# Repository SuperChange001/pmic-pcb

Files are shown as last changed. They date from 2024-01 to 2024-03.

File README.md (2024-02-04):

# Elastic Power Module

This repository contains the design and related files for the Elastic Power Module.

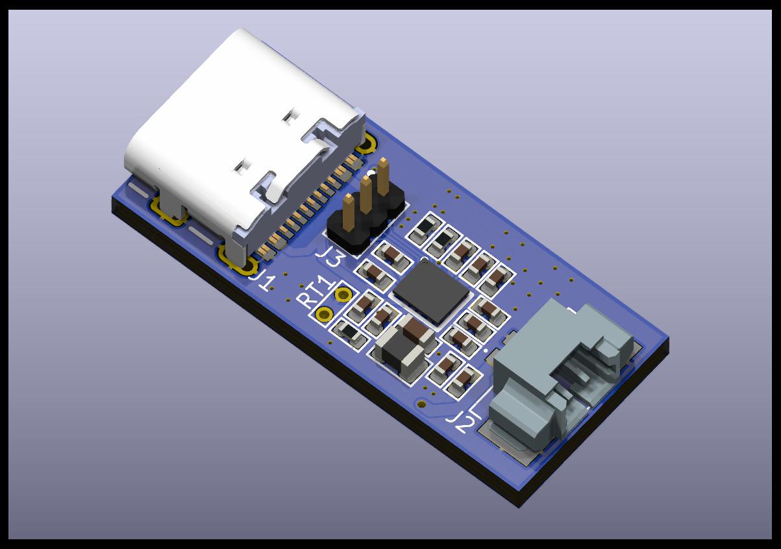
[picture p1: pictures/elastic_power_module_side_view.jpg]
Elastic Power Module


## Current Status
- [x] Schematic
- [x] PCB Design
- [x] Prototype
- [ ] Testing (** It is not tested yet, DO NOT use it as your reference design! **)
  - know issues:
    - in the default configuration, the nRST pin should be pulled up to VSYS, but right now it is floating.
      - should further check if I always need to have the external pull-up resistor or I can use the internal pull-up resistor of the microcontroller.
      - and how convinent it is to keep current circuit and configure the IC via microcontroller.
    - VIO should be connected to the header or a test pad, so we can configure the IC without flying a wire.

## Project Structure

- `elastic_power_module.kicad_pcb`: KiCad PCB design file.
- `elastic_power_module.kicad_prl`: KiCad project local settings file.
- `elastic_power_module.kicad_pro`: KiCad project file.
- `elastic_power_module.kicad_sch`: KiCad schematic file.
- `elastic_power_module.pdf`: PDF version of the schematic.
- `fp-info-cache`: Footprint info cache.
- `pictures`: Contains pictures of the assembled module.
  - `elastic_power_module_bottom_view.jpg`: Bottom view of the module.
  - `elastic_power_module_side_view.jpg`: Side view of the module.
  - `elastic_power_module_top_view.jpg`: Top view of the module.~

## Getting Started

- To get started with this project, clone the repository and open the `.kicad_pcb` or `.kicad_sch` files in KiCad.
- Or you can just download the PDF version of the schematic and use it as your reference design.
- To assemble the module, you can use the interactive BOM file [here](https://htmlpreview.github.io/?https://github.com/SuperChange001/pmic-pcb/blob/master/bom/ibom.html).

## Contributing

Contributions are welcome. Please open an issue to discuss your idea or submit a Pull Request.

## License

[MIT](https://choosealicense.com/licenses/mit/)~~~

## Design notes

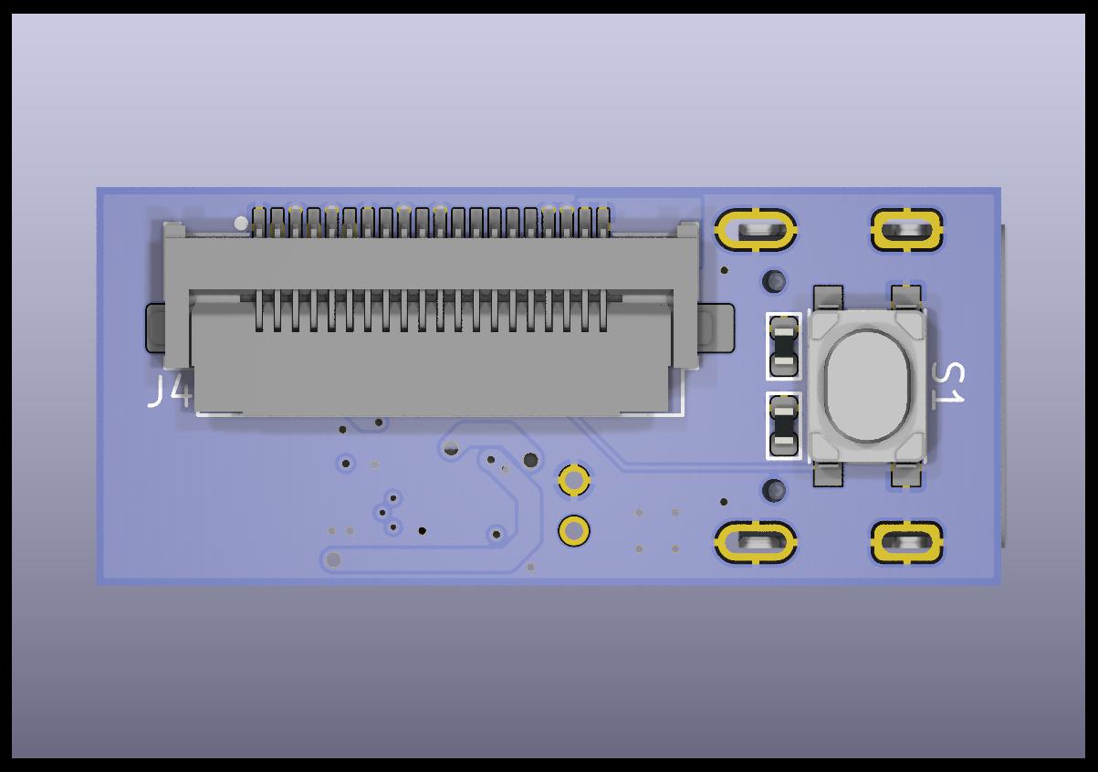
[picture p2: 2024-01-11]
pictures/elastic_power_module_bottom_view.jpg

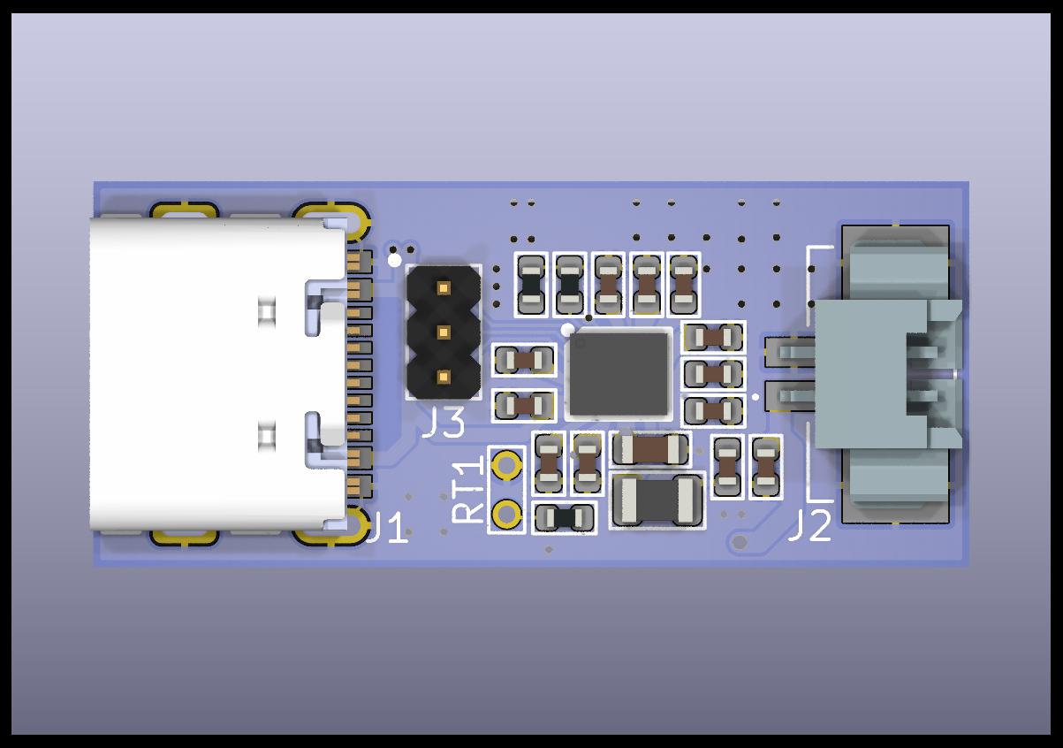
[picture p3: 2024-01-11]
pictures/elastic_power_module_top_view.jpg

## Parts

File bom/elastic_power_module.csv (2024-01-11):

null | Sourced | Placed | References | Value | Footprint | Quantity
1 |  |  | C1, C2, C3, C10, C15 | 22uF | C_0402 | 5
2 |  |  | C6, C7, C13, C14 | 1uF | C_0402 | 4
3 |  |  | C9, C12 | 4.7uF | C_0402 | 2
4 |  |  | C4 | 22uF | C_0603 | 1
5 |  |  | C5 | 3300pF | C_0402 | 1
6 |  |  | R4, R5 | 5K | R_0402 | 2
7 |  |  | R8, R9 | 10K | R_0402 | 2
8 |  |  | R10 | 100K | R_0402 | 1
9 |  |  | L1 | DFE201612E-2R2M | L_0806 | 1
10 |  |  | U1 | MAX77654AENV+T | BGA30C40P6X5_279X234X50 | 1
11 |  |  | RT1 | NTCLE413E2103H400 | THT2 | 1
12 |  |  | S1 | TL3365AF180QG | TL3365AF180QG | 1
13 |  |  | J1 | USB4105GFA060 | GCT_USB4105GFA060 | 1
14 |  |  | J2 | 53261-0271 | 53261-0271 | 1
15 |  |  | J3 | ~ | Header_THT_1.27_3P | 1
16 |  |  | J4 | ~ | Connector_20PIN_5052782033 | 1

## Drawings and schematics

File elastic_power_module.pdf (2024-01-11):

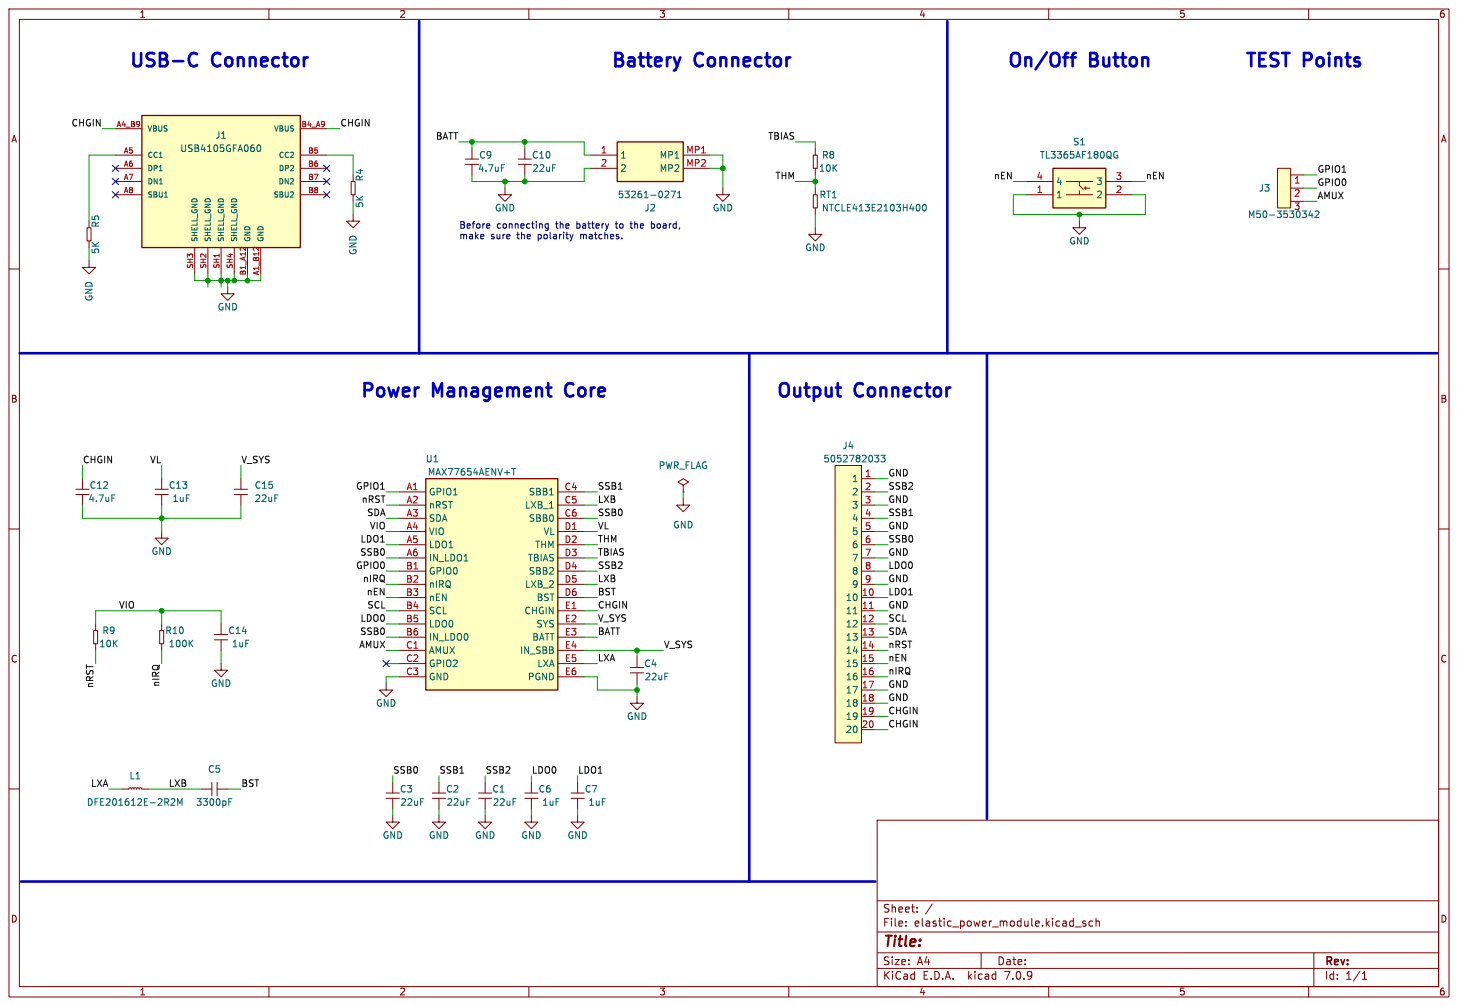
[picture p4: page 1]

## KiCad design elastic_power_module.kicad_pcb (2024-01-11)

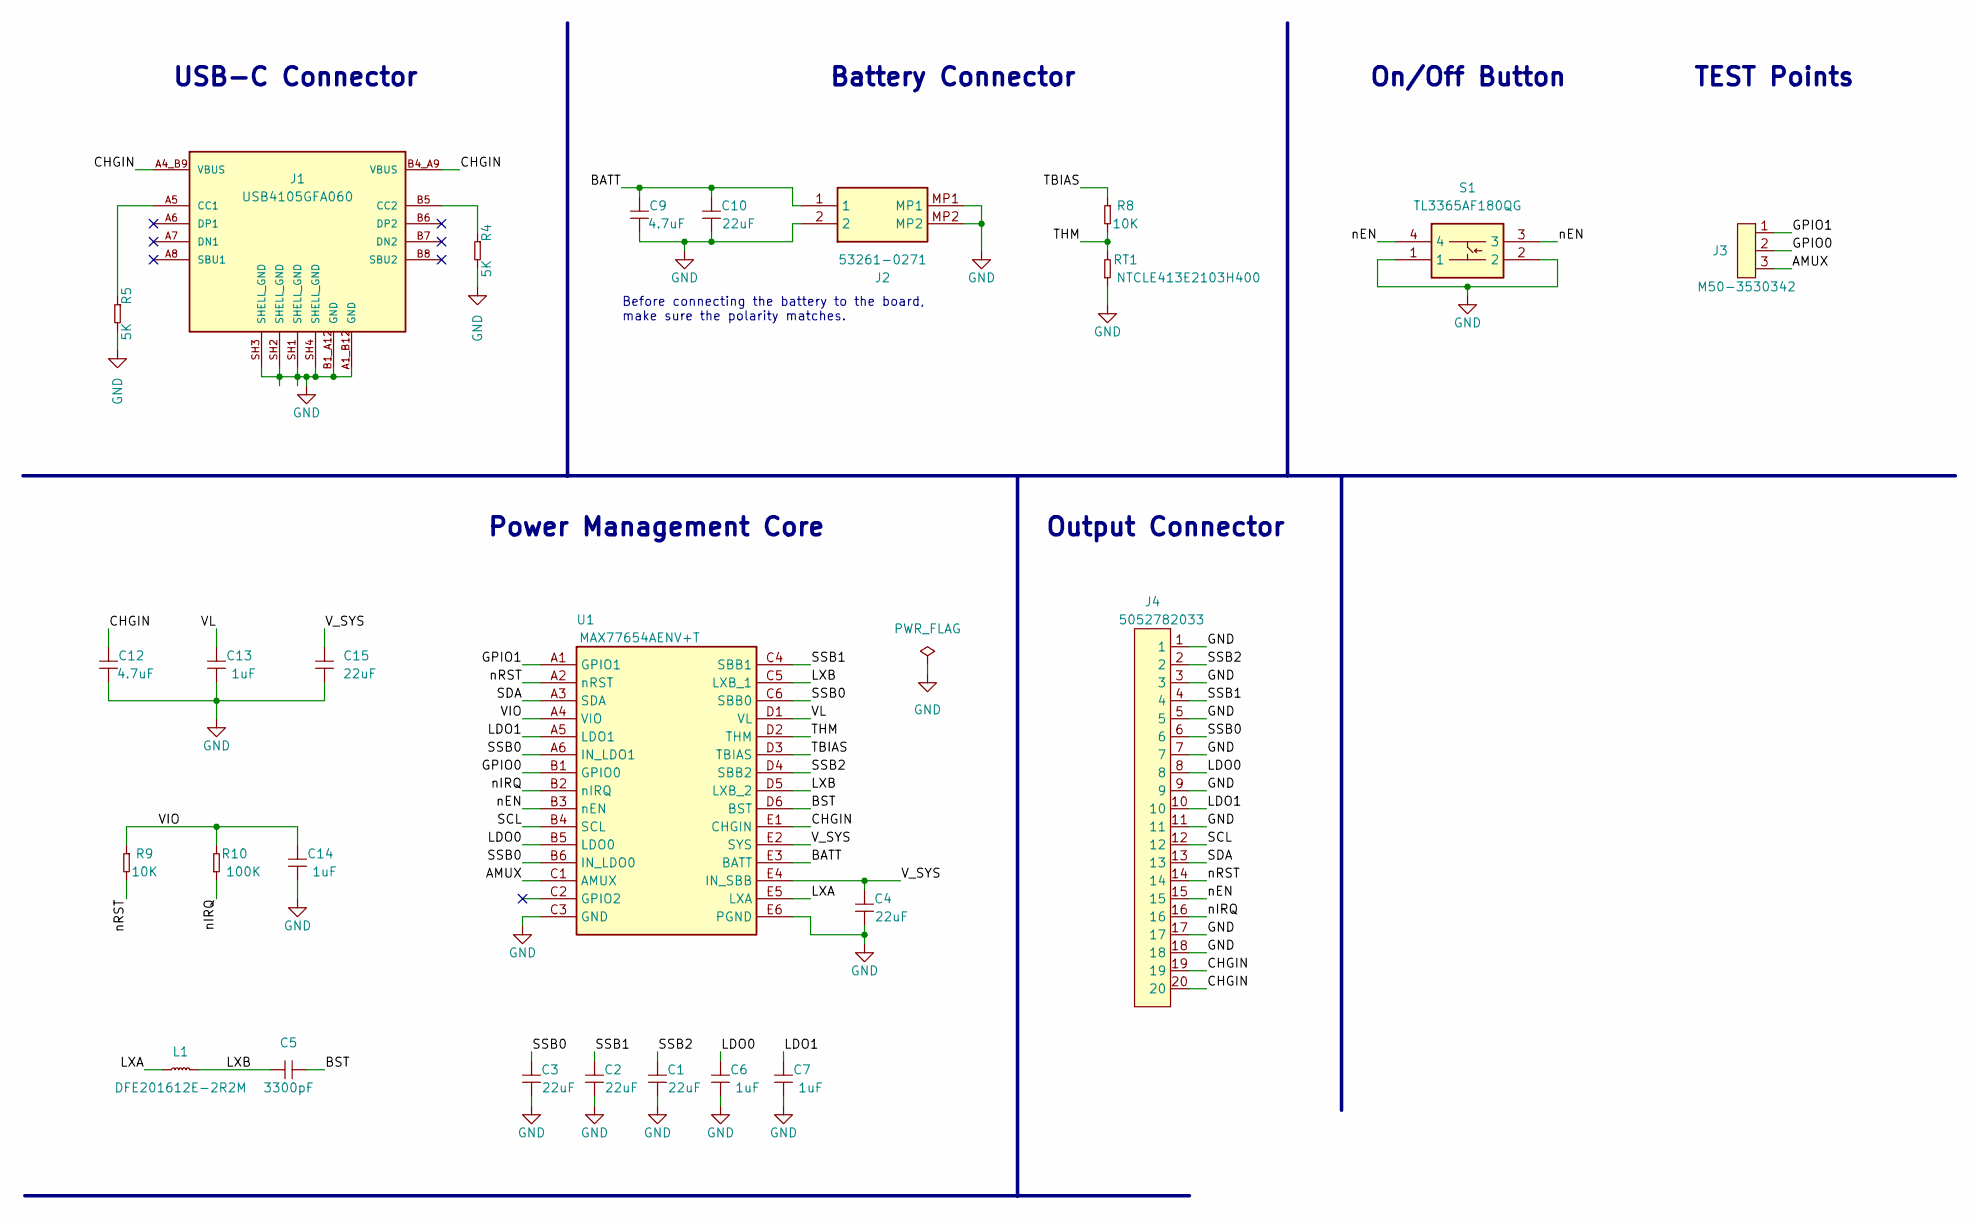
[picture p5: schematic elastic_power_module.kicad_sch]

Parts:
C1, C2, C3, C10, C15: 22uF; C_0402
C4: 22uF; C_0603
C5: 3300pF; C_0402
C6, C7, C13, C14: 1uF; C_0402
C9, C12: 4.7uF; C_0402
J1: USB4105GFA060; GCT_USB4105GFA060
J2: 53261-0271; Mouser Part Number 538-53261-0271
J3: M50-3530342; Header_THT_1.27_3P
J4: 5052782033; Connector_20PIN_5052782033
L1: DFE201612E-2R2M; L_0806
R4, R5: 5K; R_0402
R8, R9: 10K; R_0402
R10: 100K; R_0402
RT1: NTCLE413E2103H400; THT2
S1: TL3365AF180QG; Mouser Part Number 612-TL3365AF180QG
U1: MAX77654AENV+T; BGA30C40P6X5_279X234X50; Mouser Part Number 700-MAX77654AENV+T

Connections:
/AMUX: J3.3, U1.C1 (AMUX)
/BATT: C9.2, C10.1, J2.1, U1.E3 (BATT)
/BST: C5.1, U1.D6 (BST)
/CHGIN: C12.2, J1.A4_B9 (VBUS), J1.B4_A9 (VBUS), J4.19, J4.20, U1.E1 (CHGIN)
/GPIO0: J3.2, U1.B1 (GPIO0)
/GPIO1: J3.1, U1.A1 (GPIO1)
/LDO0: C6.1, J4.8, U1.B5 (LDO0)
/LDO1: C7.1, J4.10, U1.A5 (LDO1)
/LXA: L1.1, U1.E5 (LXA)
/LXB: C5.2, L1.2, U1.C5 (LXB_1), U1.D5 (LXB_2)
/SCL: J4.12, U1.B4 (SCL)
/SDA: J4.13, U1.A3 (SDA)
/SSB0: C3.1, J4.6, U1.A6 (IN_LDO1), U1.B6 (IN_LDO0), U1.C6 (SBB0)
/SSB1: C2.1, J4.4, U1.C4 (SBB1)
/SSB2: C1.1, J4.2, U1.D4 (SBB2)
/TBIAS: R8.2, U1.D3 (TBIAS)
/THM: R8.1, RT1.1, U1.D2 (THM)
/VIO: C14.1, R9.2, R10.1, U1.A4 (VIO)
/VL: C13.1, U1.D1 (VL)
/V_SYS: C4.1, C15.1, U1.E2 (SYS), U1.E4 (IN_SBB)
/nEN: J4.15, S1.3, S1.4, U1.B3 (nEN)
/nIRQ: J4.16, R10.2, U1.B2 (nIRQ)
/nRST: J4.14, R9.1, U1.A2 (nRST)
GND: C1.2, C2.2, C3.2, C4.2, C6.2, C7.2, C9.1, C10.2, C12.1, C13.2, C14.2, C15.2, J1.A1_B12 (GND), J1.B1_A12 (GND), J1.SH1 (SHELL_GND), J1.SH2 (SHELL_GND), J1.SH3 (SHELL_GND), J1.SH4 (SHELL_GND), J2.2, J2.MP1, J2.MP2, J4.1, J4.3, J4.5, J4.7, J4.9, J4.11, J4.17, J4.18, R4.1, R5.1, RT1.2, S1.1, S1.2, U1.C3 (GND), U1.E6 (PGND)
unnamed: J1.A5 (CC1), R5.2
unnamed: J1.B5 (CC2), R4.2

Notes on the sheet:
TEST Points
Output Connector
Battery Connector
USB-C Connector
On/Off Button
Power Management Core
Before connecting the battery to the board, make sure the polarity matches.

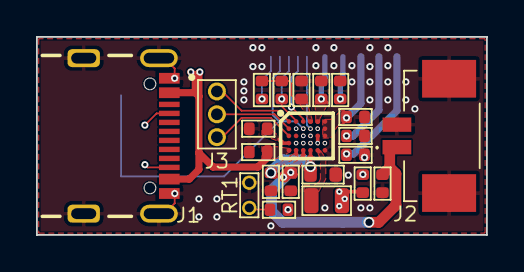
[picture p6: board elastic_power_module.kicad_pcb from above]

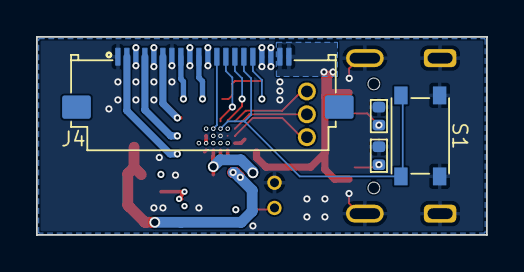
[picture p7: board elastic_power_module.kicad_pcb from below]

Board: 4 copper layers, 25.0 x 11.0 mm, 26 parts (4 on the bottom side), 26 nets.

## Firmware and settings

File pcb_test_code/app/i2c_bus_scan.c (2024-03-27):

/**
 * Copyright (c) 2020 Raspberry Pi (Trading) Ltd.
 *
 * SPDX-License-Identifier: BSD-3-Clause
 */

// Sweep through all 7-bit I2C addresses, to see if any slaves are present on
// the I2C bus. Print out a table that looks like this:
//
// I2C Bus Scan
//   0  1  2  3  4  5  6  7  8  9  A  B  C  D  E  F
// 0
// 1       @
// 2
// 3             @
// 4
// 5
// 6
// 7

// ================
// Wiring, using I2C1
// ================
// PICO     PMIC
// 26    ->  SDA 
// 27    ->  SCL
// 
#include <stdio.h>
#include "pico/stdlib.h"
#include "hardware/i2c.h"

int main() {
    // Enable UART so we can print status output
    stdio_init_all();

    // This example will use I2C0 on the default SDA and SCL pins (0, 1 on a Pico)
    i2c_init(i2c1, 1 * 100);
    gpio_set_function(26, GPIO_FUNC_I2C);
    gpio_set_function(27, GPIO_FUNC_I2C);
    gpio_pull_up(26);
    gpio_pull_up(27);

    while (1)
    {
        char c = getchar_timeout_us(10000);
        if (c == 't')
        {
            printf("\nI2C Bus Scan\n");
            printf("   0  1  2  3  4  5  6  7  8  9  A  B  C  D  E  F\n");

            for (int addr = 0; addr < (1 << 7); ++addr) {
                if (addr % 16 == 0) {
                    printf("%02x ", addr);
                }

                // Perform a 1-byte dummy read from the probe address. If a slave
                // acknowledges this address, the function returns the number of bytes
                // transferred. If the address byte is ignored, the function returns
                // -1.

                int ret;
                uint8_t rxdata;
                ret = i2c_read_blocking(i2c1, addr, &rxdata, 1, false);

                printf(ret < 0 ? "." : "@");
                printf(addr % 16 == 15 ? "\n" : "  ");
            }
            printf("Done.\n");
        }
    }
}

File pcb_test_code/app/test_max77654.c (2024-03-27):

/**
 * Copyright (c) 2020 Raspberry Pi (Trading) Ltd.
 *
 * SPDX-License-Identifier: BSD-3-Clause
 */

// ================
// Wiring, using I2C1
// ================
// PICO     PMIC
// 26    ->  SDA 
// 27    ->  SCL
// 
#include <stdio.h>
#include "pico/stdlib.h"
#include "hardware/i2c.h"
#include "max77654.h"

int main() {
    // Enable UART so we can print status output
    stdio_init_all();

    // This example will use I2C0 on the default SDA and SCL pins (0, 1 on a Pico)
    // max77654_init(i2c1);

    while (1)
    {
        char c = getchar_timeout_us(10000);
        if (c == 't')
        {
            printf("\nStart test the MAX77654\n");
            int ret = max77654_init(i2c1);
            if (ret < 0)
            {
                printf("MAX77654 is not on the bus\n");
            }
            else
            {
                printf("MAX77654 is on the bus\n");
            }
            printf("Done.\n");
        }
        else if (c == '1')
        {
            printf("Enable all SSBs\n");
            SSBx_enable(1, true);
            SSBx_enable(0, true);
            SSBx_enable(2, true);
        }
        else if (c == '2')
        {
            printf("Disable all SSBs\n");
            SSBx_enable(1, false);
            SSBx_enable(0, false);
            SSBx_enable(2, false);
        }
        else if(c == '3')
        {
            printf("Set SSB1 to 3.3V, other SSB to 1.0V\n");
            SSBx_set_voltage(1, 3300);
            SSBx_set_voltage(0, 1000);
            SSBx_set_voltage(2, 1000);
        }
        else if(c == '4')
        {
            printf("Set SSB1 to 1.0V, other SSB to 3.3V\n");
            SSBx_set_voltage(1, 1000);
            SSBx_set_voltage(0, 3300);
            SSBx_set_voltage(2, 3300);
        }
        
    }
}

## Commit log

2023-12-18 half way of the prototype
    [voltage_board.kicad_pcb, voltage_board.kicad_sch]
2023-12-18 schematic finished
    [voltage_board.kicad_pcb, voltage_board.kicad_sch]
2023-12-19 layout almost finished
    [voltage_board.kicad_pcb, voltage_board.kicad_sch]
2023-12-20 almost done the PCB
    [voltage_board.kicad_pcb, voltage_board.kicad_sch]
2024-01-11 done ;).
    [voltage_board.kicad_pcb, voltage_board.kicad_sch]
2024-01-11 optimize footprints
    [voltage_board.kicad_pcb]
2024-01-11 add bom
    [elastic_power_module.csv, elastic_power_module.kicad_pcb, elastic_power_module.kicad_sch]
2024-01-11 remove useless files
    [voltage_board.kicad_pcb, voltage_board.kicad_sch]
2024-01-11 update pcb file
    [elastic_power_module.kicad_pcb]
2024-01-11 update schematic
    [elastic_power_module.kicad_sch]
2024-03-27 add tested code, and the PMIC board works, but needs improvements
